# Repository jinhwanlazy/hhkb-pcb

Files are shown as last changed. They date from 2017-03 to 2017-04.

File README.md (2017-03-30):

# Features
- Exactly same layout as original HHKB pro 2 (especially 6u space bar).
- Compatible with [TMK firmware](https://github.com/tmk/tmk_keyboard).
- Comaptible with any Cherry MX copy switches.
- Single sided board with SMD components
- Wide tracks(excellent for home fabrication)

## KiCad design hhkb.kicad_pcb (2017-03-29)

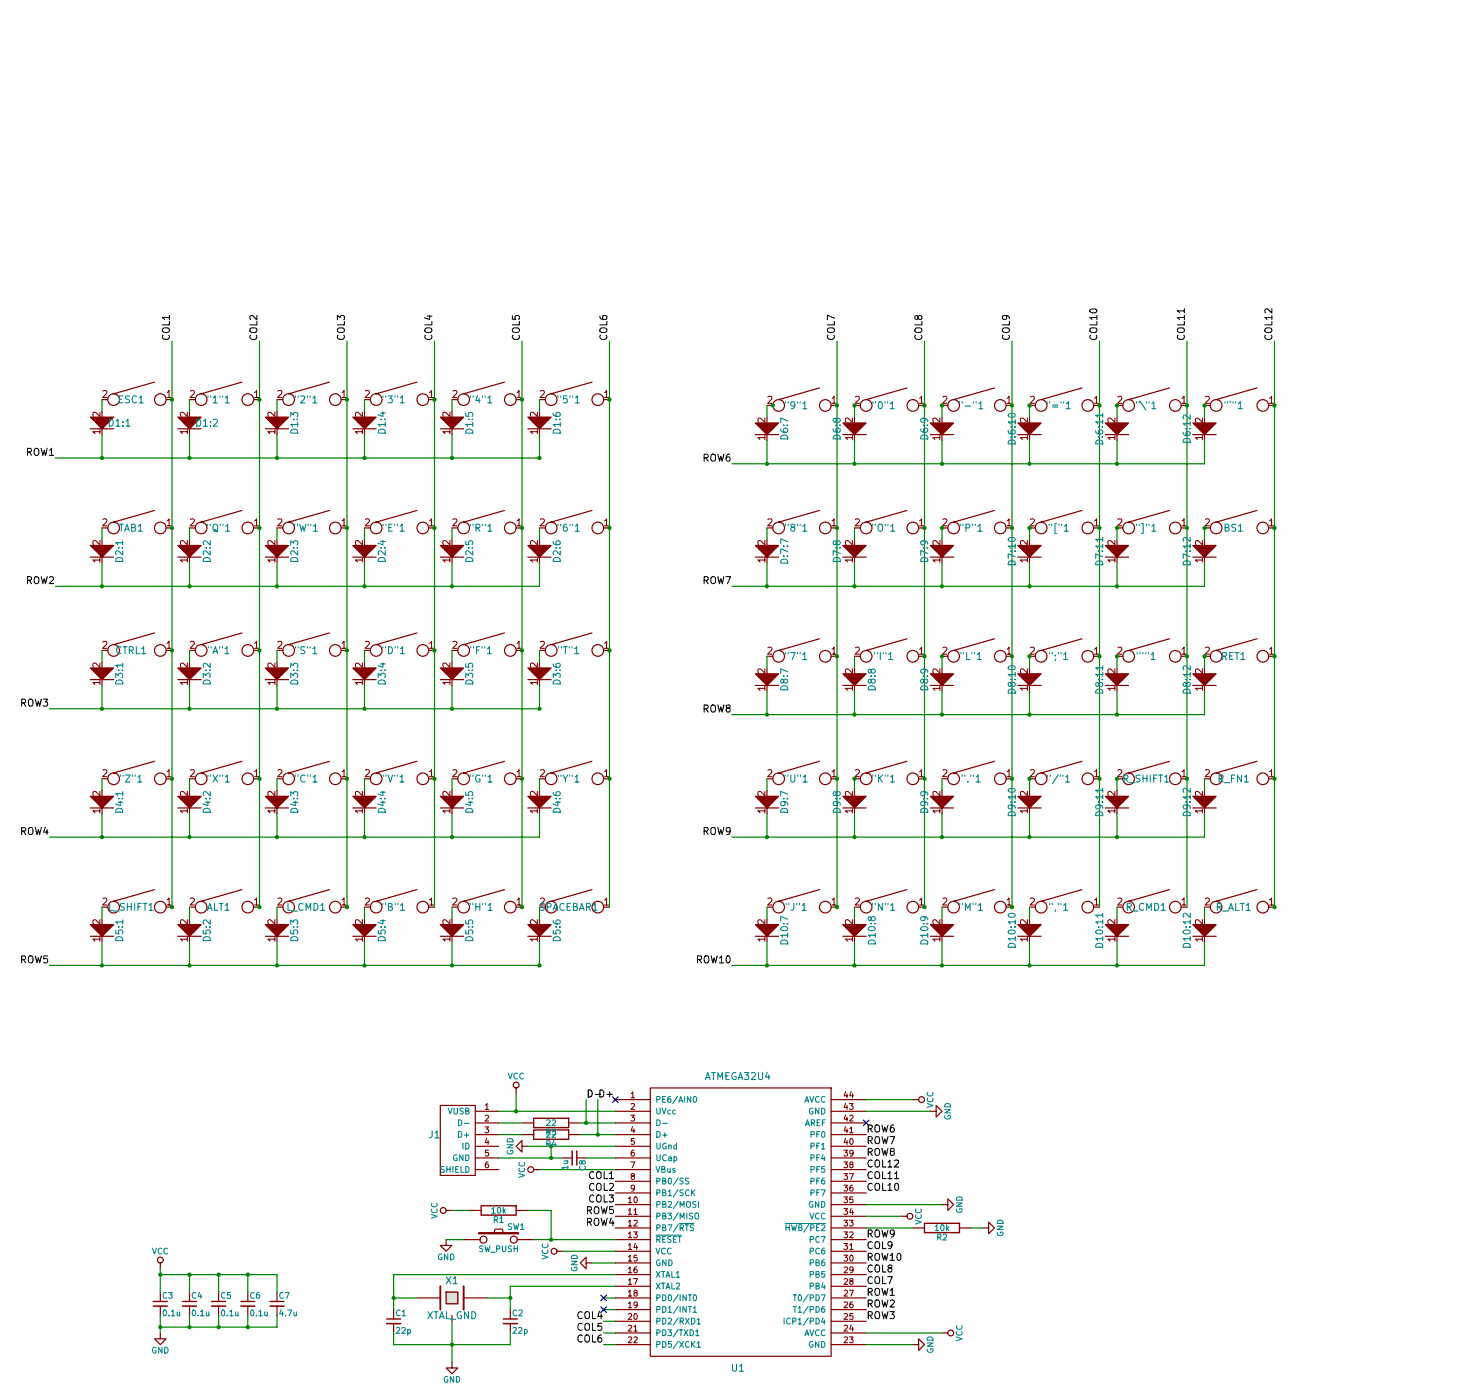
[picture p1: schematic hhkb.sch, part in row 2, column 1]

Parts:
"0"1, "1"1, "2"1, "3"1, "4"1, "5"1, "6"1, "7"1, "8"1, "9"1, "."1: KEYSW; MX_Plate_100H
"'"1: KEYSW; MX_Plate_100H
","1: KEYSW; MX_Plate_100H
"-"1: KEYSW; MX_Plate_100H
"/"1: KEYSW; MX_Plate_100H
";"1: KEYSW; MX_Plate_100H
"="1: KEYSW; MX_Plate_100H
"A"1: KEYSW; MX_Plate_100H
"B"1: KEYSW; MX_Plate_100H
"C"1: KEYSW; MX_Plate_100H
"D"1: KEYSW; MX_Plate_100H
"E"1: KEYSW; MX_Plate_100H
"F"1: KEYSW; MX_Plate_100H
"G"1: KEYSW; MX_Plate_100H
"H"1: KEYSW; MX_Plate_100H
"I"1: KEYSW; MX_Plate_100H
"J"1: KEYSW; MX_Plate_100H
"K"1: KEYSW; MX_Plate_100H
"L"1: KEYSW; MX_Plate_100H
"M"1: KEYSW; MX_Plate_100H
"N"1: KEYSW; MX_Plate_100H
"O"1: KEYSW; MX_Plate_100H
"P"1: KEYSW; MX_Plate_100H
"Q"1: KEYSW; MX_Plate_100H
"R"1: KEYSW; MX_Plate_100H
"S"1: KEYSW; MX_Plate_100H
"T"1: KEYSW; MX_Plate_100H
"U"1: KEYSW; MX_Plate_100H
"V"1: KEYSW; MX_Plate_100H
"W"1: KEYSW; MX_Plate_100H
"X"1: KEYSW; MX_Plate_100H
"Y"1: KEYSW; MX_Plate_100H
"Z"1: KEYSW; MX_Plate_100H
"["1: KEYSW; MX_Plate_100H
"\"1: KEYSW; MX_Plate_100H
"]"1: KEYSW; MX_Plate_100H
"`"1: KEYSW; MX_Plate_100H
ALT1: KEYSW; MX_Plate_100H
BS1: KEYSW; MX_Plate_150H
C1, C2: 22p; C_0805_HandSoldering
C3, C4, C5, C6: 0.1u; C_0805_HandSoldering
C7: 4.7u; C_0805_HandSoldering
C8: 1u; C_0805_HandSoldering
CTRL1: KEYSW; MX_Plate_175H
D1:1, D1:2, D1:3, D1:4, D1:5, D1:6, D2:1, D2:2, D2:3, D2:4, D2:5, D2:6, D3:1, D3:2, D3:3, D3:4, D3:5, D3:6, D4:1, D4:2, D4:3, D4:4, D4:5, D4:6, D5:1, D5:2, D5:3, D5:4, D5:5, D5:6, D6:7, D6:8, D6:9, D6:12, D7:8, D7:9, D7:10, D7:11, D7:12, D8:7, D8:8, D8:9, D8:10, D8:11, D8:12, D9:7, D9:8, D9:9, D9:10, D9:11, D9:12, D10:7, D10:8, D10:9, D10:10, D10:11, D10:12: D; D_SOD-123
D:6:10, D:6:11, D:7:7: D; D_SOD-123
ESC1: KEYSW; MX_Plate_100H
J1: USB_mini_micro_B; USB_miniB_hirose_5S8
L_CMD1: KEYSW; MX_Plate_150H
L_SHIFT1: KEYSW; MX_Plate_225H
R1, R2: 10k; R_0805_HandSoldering
R3, R4: 22; R_0805_HandSoldering
RET1: KEYSW; MX_Plate_225H
R_ALT1: KEYSW; MX_Plate_100H
R_CMD1: KEYSW; MX_Plate_150H
R_FN1: KEYSW; MX_Plate_100H
R_SHIFT1: KEYSW; MX_Plate_175H
SPACEBAR1: KEYSW; MX_Plate_600H_Stepped
SW1: SW_PUSH; SW_SPST_TL3342
TAB1: KEYSW; MX_Plate_150H
U1: ATMEGA32U4; TQFP-44_10x10mm_Pitch0.8mm
X1: XTAL_GND; FA-238

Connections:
/COL1: "Z"1.1, CTRL1.1, ESC1.1, L_SHIFT1.1, TAB1.1, U1.8 (PB0/SS)
/COL2: "1"1.1, "A"1.1, "Q"1.1, "X"1.1, ALT1.1, U1.9 (PB1/SCK)
/COL3: "2"1.1, "C"1.1, "S"1.1, "W"1.1, L_CMD1.1, U1.10 (PB2/MOSI)
/COL4: "3"1.1, "B"1.1, "D"1.1, "E"1.1, "V"1.1, U1.20 (PD2/RXD1)
/COL5: "4"1.1, "F"1.1, "G"1.1, "H"1.1, "R"1.1, U1.21 (PD3/TXD1)
/COL6: "5"1.1, "6"1.1, "T"1.1, "Y"1.1, SPACEBAR1.1, U1.22 (PD5/XCK1)
/COL7: "7"1.1, "8"1.1, "9"1.1, "J"1.1, "U"1.1, U1.28 (PB4)
/COL8: "0"1.1, "I"1.1, "K"1.1, "N"1.1, "O"1.1, U1.29 (PB5)
/COL9: "-"1.1, "."1.1, "L"1.1, "M"1.1, "P"1.1, U1.31 (PC6)
/COL10: ","1.1, "/"1.1, ";"1.1, "="1.1, "["1.1, U1.36 (PF7)
/COL11: "'"1.1, "\"1.1, "]"1.1, R_CMD1.1, R_SHIFT1.1, U1.37 (PF6)
/COL12: "`"1.1, BS1.1, RET1.1, R_ALT1.1, R_FN1.1, U1.38 (PF5)
/D+: R4.1, U1.4 (D+)
/D-: R3.1, U1.3 (D-)
/ROW1: D1:1.1, D1:2.1, D1:3.1, D1:4.1, D1:5.1, D1:6.1, U1.27 (T0/PD7)
/ROW2: D2:1.1, D2:2.1, D2:3.1, D2:4.1, D2:5.1, D2:6.1, U1.26 (T1/PD6)
/ROW3: D3:1.1, D3:2.1, D3:3.1, D3:4.1, D3:5.1, D3:6.1, U1.25 (ICP1/PD4)
/ROW4: D4:1.1, D4:2.1, D4:3.1, D4:4.1, D4:5.1, D4:6.1, U1.12 (PB7/~RTS)
/ROW5: D5:1.1, D5:2.1, D5:3.1, D5:4.1, D5:5.1, D5:6.1, U1.11 (PB3/MISO)
/ROW6: D6:7.1, D6:8.1, D6:9.1, D6:12.1, D:6:10.1, D:6:11.1, U1.41 (PF0)
/ROW7: D7:8.1, D7:9.1, D7:10.1, D7:11.1, D7:12.1, D:7:7.1, U1.40 (PF1)
/ROW8: D8:7.1, D8:8.1, D8:9.1, D8:10.1, D8:11.1, D8:12.1, U1.39 (PF4)
/ROW9: D9:7.1, D9:8.1, D9:9.1, D9:10.1, D9:11.1, D9:12.1, U1.32 (PC7)
/ROW10: D10:7.1, D10:8.1, D10:9.1, D10:10.1, D10:11.1, D10:12.1, U1.30 (PB6)
GND: C1.2, C2.2, C3.2, C4.2, C5.2, C6.2, C7.2, C8.2, J1.5 (GND), R2.1, SW1.1, U1.5 (UGnd), U1.15 (GND), U1.23 (GND), U1.35 (GND), U1.43 (GND), X1.3
unnamed: "0"1.2, D6:8.2
unnamed: "1"1.2, D1:2.2
unnamed: "2"1.2, D1:3.2
unnamed: "3"1.2, D1:4.2
unnamed: "4"1.2, D1:5.2
unnamed: "5"1.2, D1:6.2
unnamed: "6"1.2, D2:6.2
unnamed: "7"1.2, D8:7.2
unnamed: "8"1.2, D:7:7.2
unnamed: "9"1.2, D6:7.2
unnamed: "'"1.2, D8:11.2
unnamed: ","1.2, D10:10.2
unnamed: "-"1.2, D6:9.2
unnamed: "."1.2, D9:9.2
unnamed: "/"1.2, D9:10.2
unnamed: ";"1.2, D8:10.2
unnamed: "="1.2, D:6:10.2
unnamed: "A"1.2, D3:2.2
unnamed: "B"1.2, D5:4.2
unnamed: "C"1.2, D4:3.2
unnamed: "D"1.2, D3:4.2
unnamed: "E"1.2, D2:4.2
unnamed: "F"1.2, D3:5.2
unnamed: "G"1.2, D4:5.2
unnamed: "H"1.2, D5:5.2
unnamed: "I"1.2, D8:8.2
unnamed: "J"1.2, D10:7.2
unnamed: "K"1.2, D9:8.2
unnamed: "L"1.2, D8:9.2
unnamed: "M"1.2, D10:9.2
unnamed: "N"1.2, D10:8.2
unnamed: "O"1.2, D7:8.2
unnamed: "P"1.2, D7:9.2
unnamed: "Q"1.2, D2:2.2
unnamed: "R"1.2, D2:5.2
unnamed: "S"1.2, D3:3.2
unnamed: "T"1.2, D3:6.2
unnamed: "U"1.2, D9:7.2
unnamed: "V"1.2, D4:4.2
unnamed: "W"1.2, D2:3.2
unnamed: "X"1.2, D4:2.2
unnamed: "Y"1.2, D4:6.2
unnamed: "Z"1.2, D4:1.2
unnamed: "["1.2, D7:10.2
unnamed: "\"1.2, D:6:11.2
unnamed: "]"1.2, D7:11.2
unnamed: "`"1.2, D6:12.2
unnamed: ALT1.2, D5:2.2
unnamed: BS1.2, D7:12.2
unnamed: C1.1, U1.16 (XTAL1), X1.1
unnamed: C2.1, U1.17 (XTAL2), X1.2
unnamed: C8.1, U1.6 (UCap)
unnamed: CTRL1.2, D3:1.2
unnamed: D1:1.2, ESC1.2
unnamed: D2:1.2, TAB1.2
unnamed: D5:1.2, L_SHIFT1.2
unnamed: D5:3.2, L_CMD1.2
unnamed: D5:6.2, SPACEBAR1.2
unnamed: D8:12.2, RET1.2
unnamed: D9:11.2, R_SHIFT1.2
unnamed: D9:12.2, R_FN1.2
unnamed: D10:11.2, R_CMD1.2
unnamed: D10:12.2, R_ALT1.2
unnamed: J1.2 (D-), R3.2
unnamed: J1.3 (D+), R4.2
unnamed: R1.1, SW1.2, U1.13 (~RESET)
unnamed: R2.2, U1.33 (~HWB/PE2)
VCC: C3.1, C4.1, C5.1, C6.1, C7.1, J1.1 (VUSB), R1.2, U1.2 (UVcc), U1.7 (VBus), U1.14 (VCC), U1.24 (AVCC), U1.34 (VCC), U1.44 (AVCC)

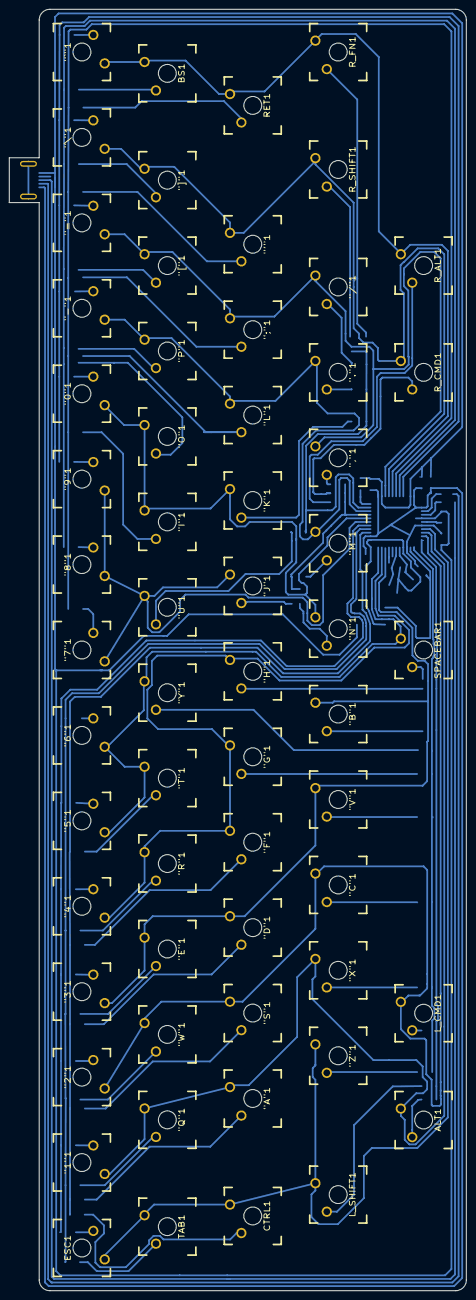
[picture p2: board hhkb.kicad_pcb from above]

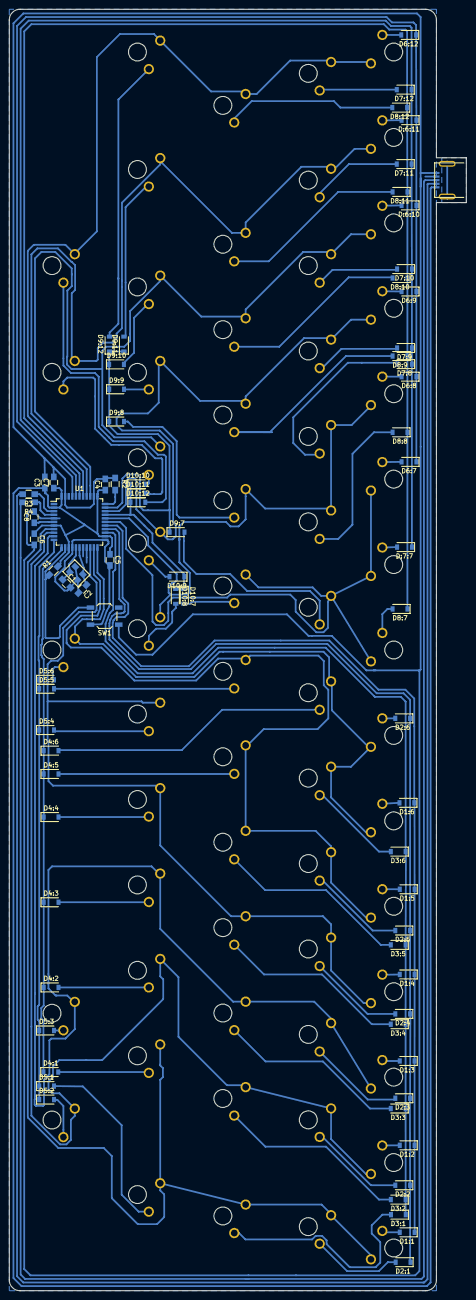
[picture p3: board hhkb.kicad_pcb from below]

Board: 2 copper layers, 101.9 x 285.8 mm, 136 parts (76 on the bottom side), 93 nets.

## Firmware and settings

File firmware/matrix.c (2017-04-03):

/*
Copyright 2012 Jun Wako <wakojun@gmail.com>

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
You should have received a copy of the GNU General Public License
along with this program.  If not, see <http://www.gnu.org/licenses/>.
*/

/*
 * scan matrix
 */
#include <stdint.h>
#include <stdbool.h>
#include <avr/io.h>
#include <util/delay.h>
#include "print.h"
#include "debug.h"
#include "util.h"
#include "matrix.h"


#ifndef DEBOUNCE
#   define DEBOUNCE	5
#endif
static uint8_t debouncing = DEBOUNCE;

/* matrix state(1:on, 0:off) */
static matrix_row_t matrix[MATRIX_ROWS];
static matrix_row_t matrix_debouncing[MATRIX_ROWS];

static matrix_row_t read_cols(void);
static void init_cols(void);
static void unselect_rows(void);
static void select_row(uint8_t row);


void matrix_init(void)
{
    // JTAG disable for PORT F. write JTD bit twice within four cycles.
    MCUCR |= (1<<JTD);
    MCUCR |= (1<<JTD);

    // initialize row and col
    unselect_rows();
    init_cols();

    // initialize matrix state: all keys off
    for (uint8_t i=0; i < MATRIX_ROWS; i++) {
        matrix[i] = 0;
        matrix_debouncing[i] = 0;
    }
}

uint8_t matrix_scan(void)
{
    for (uint8_t i = 0; i < MATRIX_ROWS; i++) {
        select_row(i);
        _delay_us(30);  // without this wait read unstable value.
        matrix_row_t cols = read_cols();
        if (matrix_debouncing[i] != cols) {
            matrix_debouncing[i] = cols;
            if (debouncing) {
                debug("bounce!: "); debug_hex(debouncing); debug("\n");
            }
            debouncing = DEBOUNCE;
        }
        unselect_rows();
    }

    if (debouncing) {
        if (--debouncing) {
            _delay_ms(1);
        } else {
            for (uint8_t i = 0; i < MATRIX_ROWS; i++) {
                matrix[i] = matrix_debouncing[i];
            }
        }
    }

    return 1;
}

inline
matrix_row_t matrix_get_row(uint8_t row)
{
    return matrix[row];
}

static void  init_cols(void)
{
    DDRB  &= ~(1<<0 | 1<<1 | 1<<2 | 1<<4 | 1<<5 | 1<<5);
    PORTB |=  (1<<0 | 1<<1 | 1<<2 | 1<<4 | 1<<5 | 1<<5);
    DDRC  &= ~(1<<6);
    PORTC |=  (1<<6);
    DDRD  &= ~(1<<2 | 1<<3 | 1<<5);
    PORTD |=  (1<<2 | 1<<3 | 1<<5);
    DDRF  &= ~(1<<5 | 1<<6 | 1<<7);
    PORTF |=  (1<<5 | 1<<6 | 1<<7);
}

/* Column pin configuration
 * col: 1   2   3   4   5   6   7   8   9   10  11  12 
 * pin: B0  B1  B2  D2  D3  D5  B4  B5  C6  F7  F6  F5
 */
static matrix_row_t read_cols(void)
{
    return (PINB&(1<<0) ? 0 : (1<<0)) |
           (PINB&(1<<1) ? 0 : (1<<1)) |
           (PINB&(1<<2) ? 0 : (1<<2)) |
           (PIND&(1<<2) ? 0 : (1<<3)) |
           (PIND&(1<<3) ? 0 : (1<<4)) |
           (PIND&(1<<5) ? 0 : (1<<5)) |
           (PINB&(1<<4) ? 0 : (1<<6)) |
           (PINB&(1<<5) ? 0 : (1<<7)) |
           (PINC&(1<<6) ? 0 : (1<<8)) |
           (PINF&(1<<7) ? 0 : (1<<9)) |
           (PINF&(1<<6) ? 0 : (1<<10))|
           (PINF&(1<<5) ? 0 : (1<<11));
}

/* Row pin configuration
 * row: 1   2   3   4   5   6   7   8   9  10
 * pin: D7  D6  D4  B7  B3  F0  F1  F4  C7 B6
 */
static void unselect_rows(void)
{
    // Hi-Z(DDR:0, PORT:0) to unselect
    DDRB  &= ~0b11001000;
    PORTB &= ~0b11001000;
    DDRC  &= ~0b10000000;
    PORTC &= ~0b10000000;
    DDRD  &= ~0b11010000;
    PORTD &= ~0b11010000;
    DDRF  &= ~0b00010011;
    PORTF &= ~0b00010011;
}

static void select_row(uint8_t row)
{
    // Output low(DDR:1, PORT:0) to select
    switch (row) {
        case 0:
            DDRD  |= (1<<7);  DDRF  |= (1<<0);
            PORTD &= ~(1<<7); PORTF &= ~(1<<0);
            break;
        case 1:
            DDRD  |= (1<<6);  DDRF  |= (1<<1);
            PORTD &= ~(1<<6); PORTF &= ~(1<<1);
            break;
        case 2:
            DDRD  |= (1<<4);  DDRF  |= (1<<4);
            PORTD &= ~(1<<4); PORTF &= ~(1<<4);
            break;
        case 3:
            DDRB  |= (1<<7);  DDRC  |= (1<<7);
            PORTB &= ~(1<<7); PORTC &= ~(1<<7);
            break;
        case 4:
            DDRB  |= (1<<3);  DDRB  |= (1<<6);
            PORTB &= ~(1<<3); PORTB &= ~(1<<6);
            break;
    }
}

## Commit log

2017-03-28 init commit
    [hhkb.kicad_pcb, hhkb.sch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]
2017-03-28 rotate 90 degree
    [hhkb.kicad_pcb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]
2017-03-28 change usb connector footprint
    [hhkb.kicad_pcb, hhkb.sch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]
2017-03-29 add firmware
    note that fn layer is temporarily disabled due to error.
    [led.c, matrix.c]
2017-03-30 minimal vim like fn layer
    I might able to mimic all vim behaviors with keymap layers,
    but I decided to keep it simple.
    However, the insert key is an exception. It is never used without
    ctrl or shift, but also it is frequently used as a super set of
    ctrl-c/v.
2017-04-03 disabling jtag solved all problems
    [matrix.c]
2017-10-06 LCTRL now is a dual perpose key, works as additional ESC when tapped

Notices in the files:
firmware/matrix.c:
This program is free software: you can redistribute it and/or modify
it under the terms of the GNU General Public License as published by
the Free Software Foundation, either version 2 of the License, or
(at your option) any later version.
